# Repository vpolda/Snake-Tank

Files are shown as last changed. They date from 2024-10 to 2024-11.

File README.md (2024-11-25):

# Snake Tank

A temperature and humidity monitoring system primarly used for reptile terrariums. 

## Description

A custom ESP32-S3 PCB for temperature and humidity monitoring, along with camera monitoring. Supports up to four (4) external DHT11 sensors. The data can either be monitored through the onboard LCD display or remotely on a wifi device through Arduino Cloud. Two ESP32 Camera modules are attached externally for live video feed.

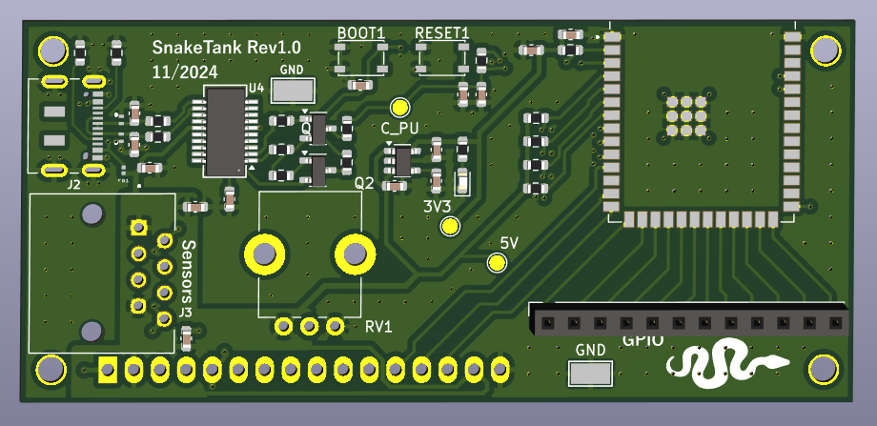
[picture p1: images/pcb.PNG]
SnakeTank PCB in KiCad 3D View SnakeTank PCB in KiCAD 3D viewer


## Design

It currently uses an ESP32-S3-WROOM-1-N8 along with module DHT11 sensors. The DHT11s where chosen for affordability and the need for general accuracy, not precision.
The DHT11 sensors are attached through an RJ45 port and an ethernet cable. These were chosen for their widely avaible nature and simplicity.
An onboard LCD screen is used to check sensor readings at any time. 
The Arduino Cloud was chosen for remote access to the available data due to ease of use and simplistic nature.

The ESP32 cameras were selected for their independence with the ability to host their own webserver or connect to another remote server. While an onboard/connection is preferred, the simpliticy and power management setup would be easier to do.

A custom four layer PCB was designed for this project using a Signal+power/GND/GND/Signal+power stackup. This was done as a learning exercise for PCB best practices. The LCD screen is on the bottom side of the board to minimize PCB size.

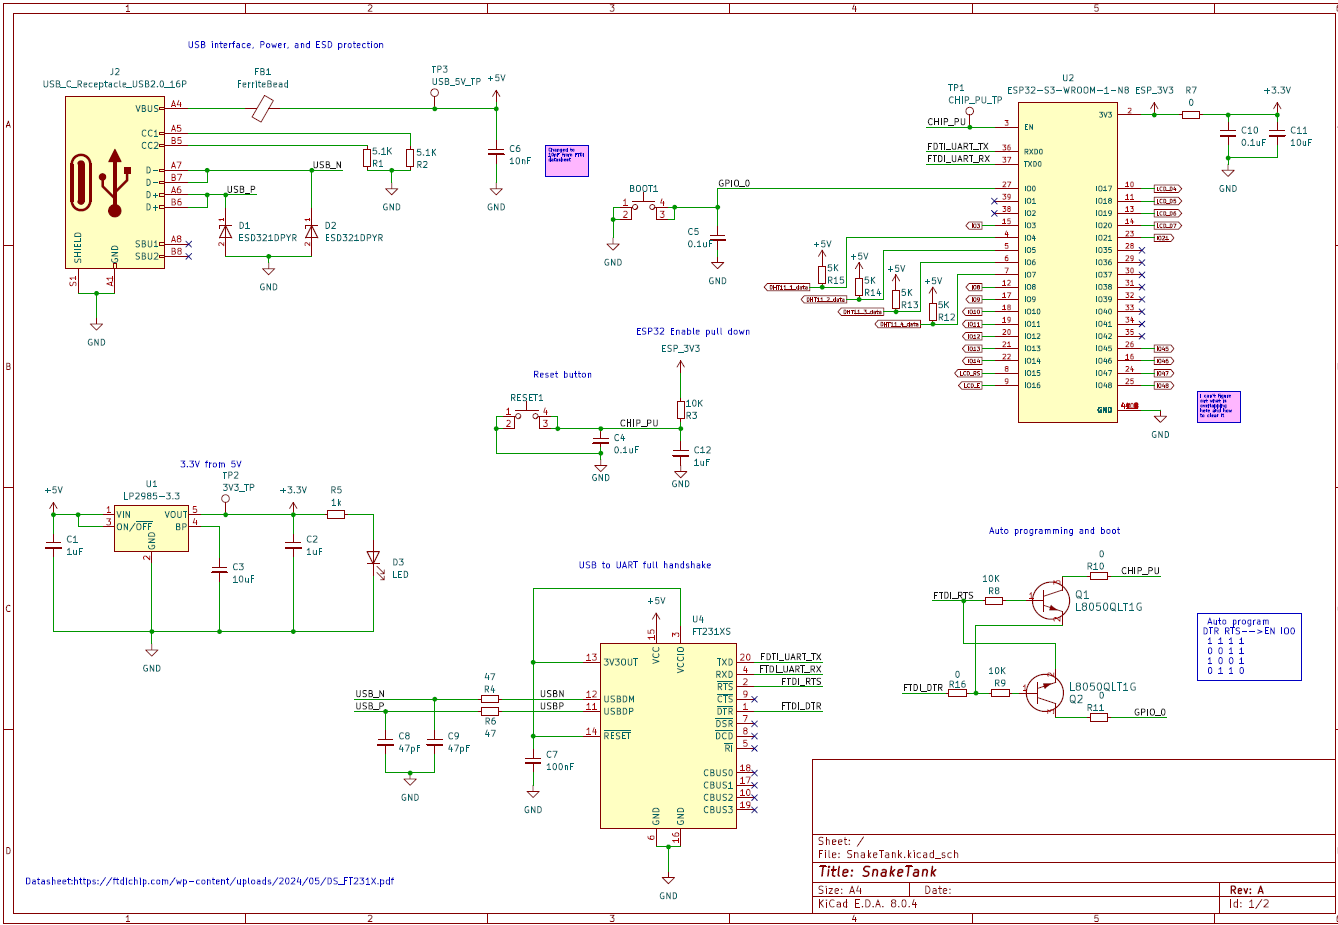
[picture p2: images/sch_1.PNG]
SnakeTank PCB Schematic Main

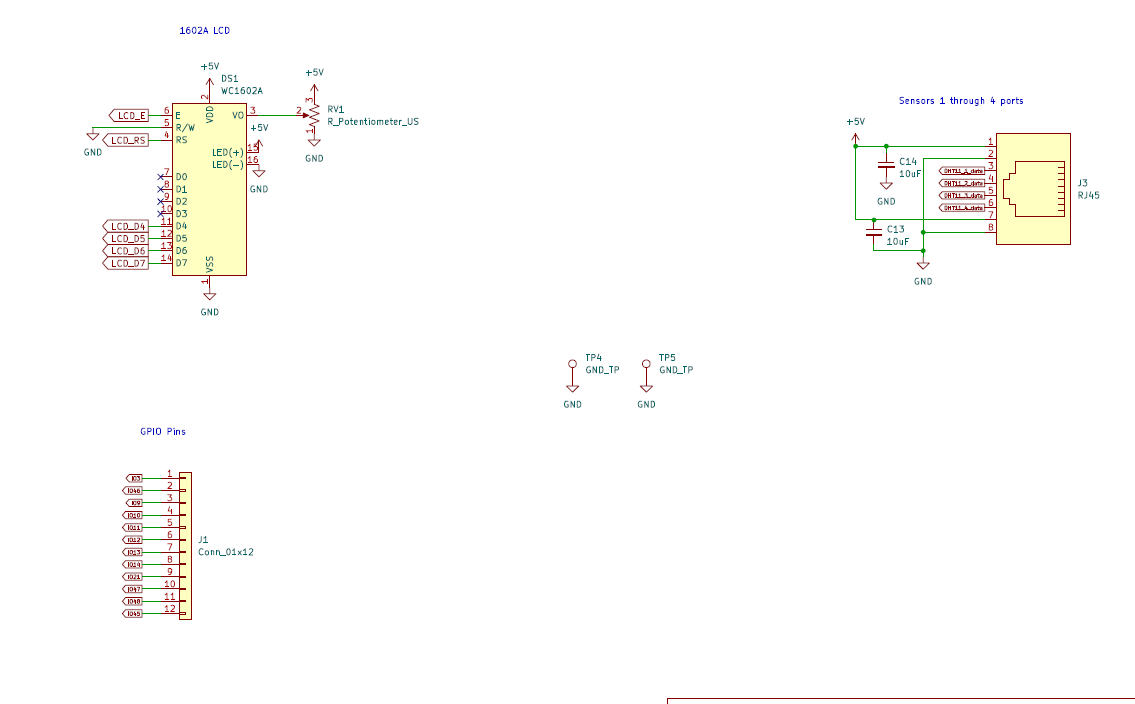
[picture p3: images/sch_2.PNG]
SnakeTank PCB Schematic Peripherals SnakeTank PCB Schematic Periphs


## Getting Started

### File Structure
- Camera - Arduino code for each ESP32 camera. 
   - ESP32_camera_webserverHost: Hosting a webserver locally on each MCU

- Hardware
   - Datasheets: Self explain
   - KiCAD: Kicad project files for custom PCB w/ ESP32
   - snakeTank_currentEstimate: Power estimate SS
 
- Software
   - Integration: combining software modules
   - OnboardDisplay: tests of the 1602A
   - LCD_interrupt: Displaying on 1602 through Arduino interrupts and timers 
   - SensorReading: reading from the dht11 modules testing
   - Camera: code for separate external esp32 cameras
  
### Dependencies

### Installing

### Executing program

## Help

## Authors

Victoria Polda
www.linkedin.com/in/victoriapolda

## Version History

* 0.1
    * Initial Release

## License

MIT License

Copyright (c) 2024 Victoria Polda

Permission is hereby granted, free of charge, to any person obtaining a copy
of this software and associated documentation files (the "Software"), to deal
in the Software without restriction, including without limitation the rights
to use, copy, modify, merge, publish, distribute, sublicense, and/or sell
copies of the Software, and to permit persons to whom the Software is
furnished to do so, subject to the following conditions:

The above copyright notice and this permission notice shall be included in all
copies or substantial portions of the Software.

THE SOFTWARE IS PROVIDED "AS IS", WITHOUT WARRANTY OF ANY KIND, EXPRESS OR
IMPLIED, INCLUDING BUT NOT LIMITED TO THE WARRANTIES OF MERCHANTABILITY,
FITNESS FOR A PARTICULAR PURPOSE AND NONINFRINGEMENT. IN NO EVENT SHALL THE
AUTHORS OR COPYRIGHT HOLDERS BE LIABLE FOR ANY CLAIM, DAMAGES OR OTHER
LIABILITY, WHETHER IN AN ACTION OF CONTRACT, TORT OR OTHERWISE, ARISING FROM,
OUT OF OR IN CONNECTION WITH THE SOFTWARE OR THE USE OR OTHER DEALINGS IN THE
SOFTWARE.

## Acknowledgments

Inspired by my Ghost corn snake Kynes :)

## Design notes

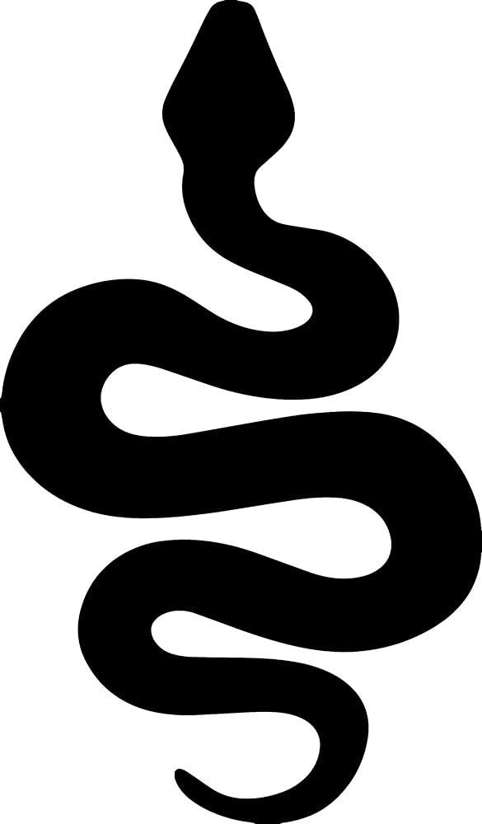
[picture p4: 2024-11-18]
Hardware/graphics/snake_filled.jpg

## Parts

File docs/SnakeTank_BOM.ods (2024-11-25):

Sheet: SnakeTank PCB
Id | Designator | Footprint | Quantity | Designation | Supplier and ref
1 | R5 | R_0603_1608Metric | 1 | 1k
2 | R16,R7,R11,R10 | R_0603_1608Metric | 4 | 0
3 | C5,C10,C4 | C_0603_1608Metric | 3 | 0.1uF
4 | C14,C3,C11,C13 | C_0603_1608Metric | 4 | 10uF
5 | RESET1,BOOT1 | SW_SPST_PTS810 | 2 | ~
6 | D3 | LED_0603_1608Metric | 1 | LED
7 | C8,C9 | C_0603_1608Metric | 2 | 47pF
8 | D2,D1 | TVS_ESD321DPYR | 2 | ESD321DPYR
9 | R13,R15,R12,R14 | R_0603_1608Metric | 4 | 5K
10 | U4 | SSOP-20_3.9x8.7mm_P0.635mm | 1 | FT231XS
11 | R1,R2 | R_0603_1608Metric | 2 | 5.1K
12 | RV1 | Potentiometer_Bourns_PTV09A-1_Single_Vertical | 1 | R_Potentiometer_US
13 | J1 | PinSocket_1x12_P2.54mm_Vertical | 1 | Conn_01x12
14 | 3V3 | TestPoint_Pad_D1.5mm | 1 | 3V3_TP
15 | C12,C2,C1 | C_0603_1608Metric | 3 | 1uF
16 | R9,R8,R3 | R_0603_1608Metric | 3 | 10K
17 | C_PU | TestPoint_Pad_D1.5mm | 1 | CHIP_PU_TP
18 | U1 | SOT-23-5 | 1 | LP2985-3.3
19 | GND,GND | TestPoint_Keystone_5019_Minature | 2 | GND_TP
20 | Q2,Q1 | SOT-23-3 | 2 | L8050QLT1G
21 | 5V | TestPoint_Pad_D1.5mm | 1 | USB_5V_TP
22 | R6,R4 | R_0603_1608Metric | 2 | 47
23 | U2 | XCVR_ESP32-S3-WROOM-1-N8 | 1 | ESP32-S3-WROOM-1-N8
24 | C7 | C_0603_1608Metric | 1 | 100nF
25 | J3 | AMPHENOL_RJE881880100 | 1 | RJ45
26 | FB1 | BEADC0603X33N | 1 | FerriteBead
27 | C6 | C_0603_1608Metric | 1 | 10nF
28 | J2 | USB_C_Receptacle_JAE_DX07S016JA1R1500 | 1 | USB_C_Receptacle_USB2.0_16P
29 | DS1 | WC1602A | 1 | WC1602A

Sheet: External
case
esp32 camera
ethernet cable
DHT11 sensor module

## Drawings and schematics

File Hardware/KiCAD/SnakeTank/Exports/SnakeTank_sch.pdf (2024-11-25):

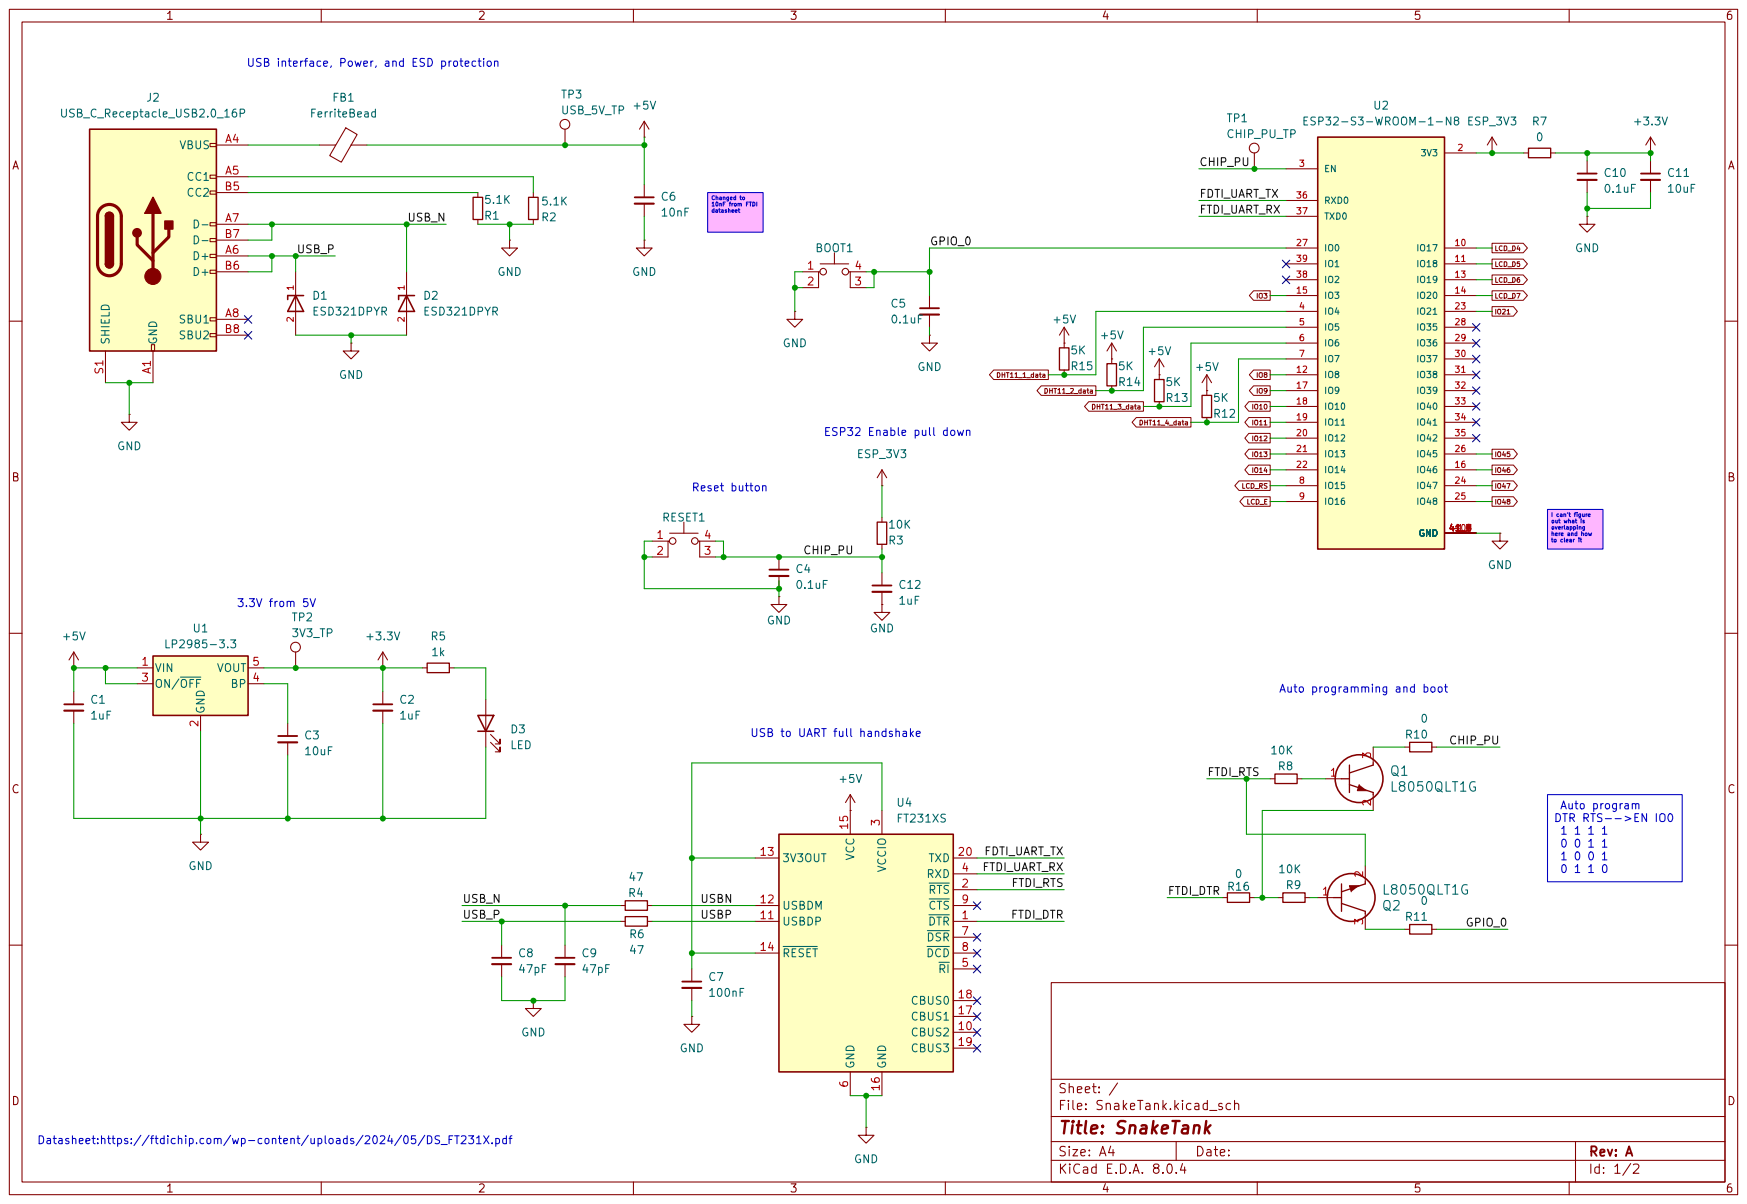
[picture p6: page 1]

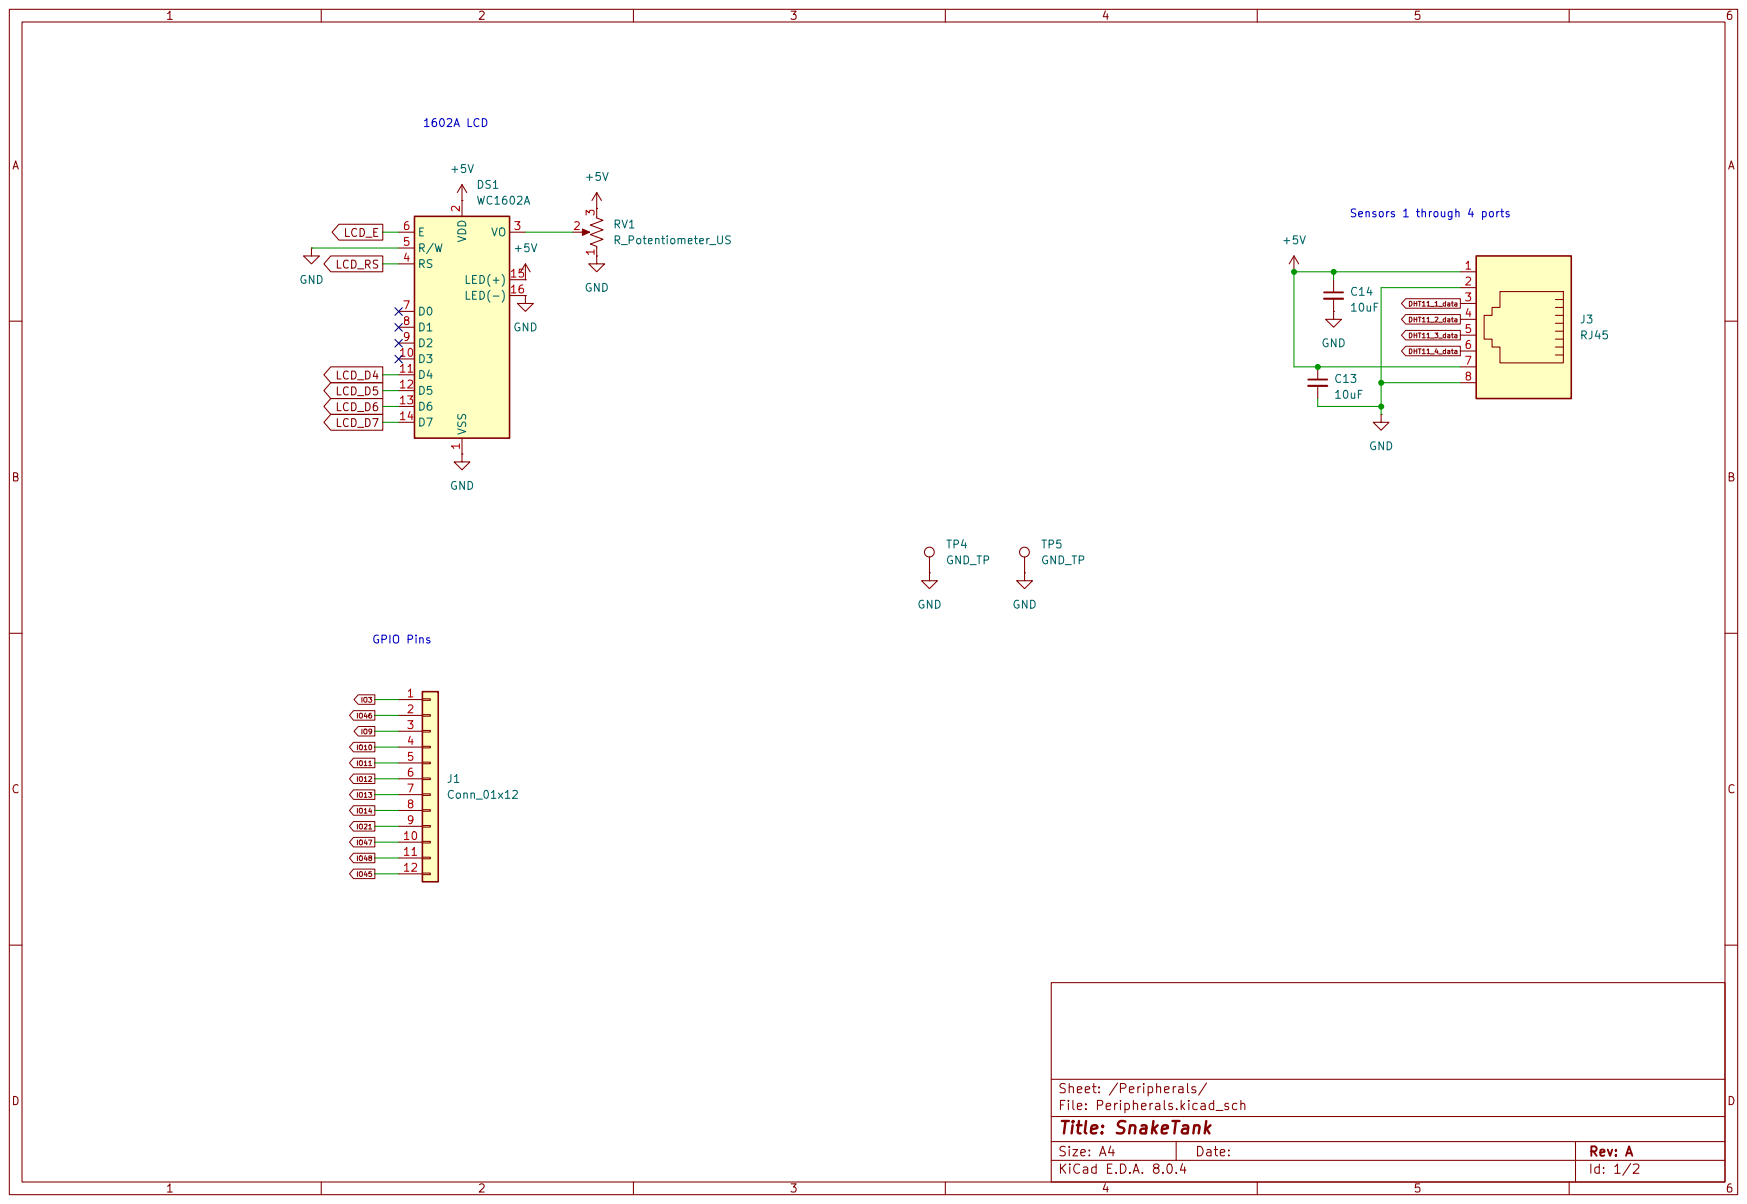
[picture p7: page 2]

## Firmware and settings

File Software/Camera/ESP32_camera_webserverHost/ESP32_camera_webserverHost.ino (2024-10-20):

//Script to connect ESP32 camera to wifi and host a server at 

// Load Wi-Fi library
#include <WiFi.h>

// Replace with your network credentials
const char* ssid = "Embedded_Government_Microchip_#1";
const char* password = "El3ctr0n1csBe4tsCS!";

// Set your Static IP address
IPAddress local_IP(192, 168, 1, 184);
// Set your Gateway IP address
IPAddress gateway(192, 168, 1, 1);
IPAddress subnet(255, 255, 0, 0);
IPAddress primaryDNS(8, 8, 8, 8); //optional
IPAddress secondaryDNS(8, 8, 4, 4); //optional

// Set web server port number to 80
WiFiServer server(80);

// Variable to store the HTTP request
String header;

// Auxiliar variables to store the current output state
String output26State = "off";
String output27State = "off";

// Assign output variables to GPIO pins
const int output26 = 26;
const int output27 = 27;

// Current time
unsigned long currentTime = millis();
// Previous time
unsigned long previousTime = 0; 
// Define timeout time in milliseconds (example: 2000ms = 2s)
const long timeoutTime = 2000;

void setup() {
  Serial.begin(115200);
  // Initialize the output variables as outputs
  pinMode(output26, OUTPUT);
  pinMode(output27, OUTPUT);
  // Set outputs to LOW
  digitalWrite(output26, LOW);
  digitalWrite(output27, LOW);

  if(!WiFi.config(local_IP, gateway, subnet, primaryDNS, secondaryDNS)) {
    Serial.println("STA Failed to configure");
  }
  WiFi.begin(ssid, password);

  // Connect to Wi-Fi network with SSID and password
  Serial.print("Connecting to ");
  Serial.println(ssid);
  WiFi.begin(ssid, password);
  while (WiFi.status() != WL_CONNECTED) {
    delay(500);
    Serial.print(".");
  }
  // Print local IP address and start web server
  Serial.println("");
  Serial.println("WiFi connected.");
  Serial.println("IP address: ");
  Serial.println(WiFi.localIP());
  server.begin();
}

void loop(){
  WiFiClient client = server.available();   // Listen for incoming clients

  if (client) {                             // If a new client connects,
    currentTime = millis();
    previousTime = currentTime;
    Serial.println("New Client.");          // print a message out in the serial port
    String currentLine = "";                // make a String to hold incoming data from the client
    while (client.connected() && currentTime - previousTime <= timeoutTime) {  // loop while the client's connected
      currentTime = millis();
      if (client.available()) {             // if there's bytes to read from the client,
        char c = client.read();             // read a byte, then
        Serial.write(c);                    // print it out the serial monitor
        header += c;
        if (c == '\n') {                    // if the byte is a newline character
          // if the current line is blank, you got two newline characters in a row.
          // that's the end of the client HTTP request, so send a response:
          if (currentLine.length() == 0) {
            // HTTP headers always start with a response code (e.g. HTTP/1.1 200 OK)
            // and a content-type so the client knows what's coming, then a blank line:
            client.println("HTTP/1.1 200 OK");
            client.println("Content-type:text/html");
            client.println("Connection: close");
            client.println();
            
            // turns the GPIOs on and off
            if (header.indexOf("GET /26/on") >= 0) {
              Serial.println("GPIO 26 on");
              output26State = "on";
              digitalWrite(output26, HIGH);
            } else if (header.indexOf("GET /26/off") >= 0) {
              Serial.println("GPIO 26 off");
              output26State = "off";
              digitalWrite(output26, LOW);
            } else if (header.indexOf("GET /27/on") >= 0) {
              Serial.println("GPIO 27 on");
              output27State = "on";
              digitalWrite(output27, HIGH);
            } else if (header.indexOf("GET /27/off") >= 0) {
              Serial.println("GPIO 27 off");
              output27State = "off";
              digitalWrite(output27, LOW);
            }
            
            // Display the HTML web page
            client.println("<!DOCTYPE html><html>");
            client.println("<head><meta name=\"viewport\" content=\"width=device-width, initial-scale=1\">");
            client.println("<link rel=\"icon\" href=\"data:,\">");
            // CSS to style the on/off buttons 
            // Feel free to change the background-color and font-size attributes to fit your preferences
            client.println("<style>html { font-family: Helvetica; display: inline-block; margin: 0px auto; text-align: center;}");
            client.println(".button { background-color: #4CAF50; border: none; color: white; padding: 16px 40px;");
            client.println("text-decoration: none; font-size: 30px; margin: 2px; cursor: pointer;}");
            client.println(".button2 {background-color: #555555;}</style></head>");
            
            // Web Page Heading
            client.println("<body><h1>ESP32 Web Server</h1>");
            
            // Display current state, and ON/OFF buttons for GPIO 26  
            client.println("<p>GPIO 26 - State " + output26State + "</p>");
            // If the output26State is off, it displays the ON button       
            if (output26State=="off") {
              client.println("<p><a href=\"/26/on\"><button class=\"button\">ON</button></a></p>");
            } else {
              client.println("<p><a href=\"/26/off\"><button class=\"button button2\">OFF</button></a></p>");
            } 
               
            // Display current state, and ON/OFF buttons for GPIO 27  
            client.println("<p>GPIO 27 - State " + output27State + "</p>");
            // If the output27State is off, it displays the ON button       
            if (output27State=="off") {
              client.println("<p><a href=\"/27/on\"><button class=\"button\">ON</button></a></p>");
            } else {
              client.println("<p><a href=\"/27/off\"><button class=\"button button2\">OFF</button></a></p>");
            }
            client.println("</body></html>");
            
            // The HTTP response ends with another blank line
            client.println();
            // Break out of the while loop
            break;
          } else { // if you got a newline, then clear currentLine
            currentLine = "";
          }
        } else if (c != '\r') {  // if you got anything else but a carriage return character,
          currentLine += c;      // add it to the end of the currentLine
        }
      }
    }
    // Clear the header variable
    header = "";
    // Close the connection
    client.stop();
    Serial.println("Client disconnected.");
    Serial.println("");
  }
}

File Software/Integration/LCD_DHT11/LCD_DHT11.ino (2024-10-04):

//This script tests updating the LCD screen based on interrupts 
//instead of the delay function

// LCD stuff
#include <LiquidCrystal.h>
 
// initialize the library with the numbers of the interface pins
//Goes RS, E, D4,D5,D6,D7
LiquidCrystal lcd(45, 35, 38, 39, 40, 41);

//Sensor stuff
#include <DHT11.h>

DHT11 dht1(4);
DHT11 dht2(6);

int temperature1 = 0;
int humidity1 = 0;

int temperature2 = 0;
int humidity2 = 0;

int result1 = 0;
int result2 = 0;

//Timer stuff
#include <SimpleTimer.h>
SimpleTimer lcdTimer(5000);

void setup()
{
  Serial.begin(115200);
  // set up the LCD's number of columns and rows (c,r), only do this once on setup
  lcd.begin(16, 2);
  //row 0 = first
  lcd.setCursor(0, 0);
  // Print a message to the LCD.
  lcd.print("Dual Reading");
  //Move to second row for data
}

void loop() {
  if (lcdTimer.isReady()) {            // Check is ready a first timer
    //Serial.println("5 seconds have passed");
    lcdTimer.reset();  

    lcd.clear();

    //Sensor 1
    //Read temp and humidity
    int result1 = dht1.readTemperatureHumidity(temperature1, humidity1);

    lcd.setCursor(0, 0);

    if (result1 == 0) {
      lcd.print("T1:");
      lcd.print(temperature1);
      lcd.print("C H1:");
      lcd.print(humidity1);
    } else {
      // Print error message based on the error code.
      lcd.print(DHT11::getErrorString(result1));
    }

    //Sensor 2
    
    //Read temp and humidity
    int result2 = dht2.readTemperatureHumidity(temperature2, humidity2);

    lcd.setCursor(0, 1);

    if (result2 == 0) {
      lcd.print("T2:");
      lcd.print(temperature2);
      lcd.print("C H2:");
      lcd.print(humidity2);
    } else {
      // Print error message based on the error code.
      lcd.print(DHT11::getErrorString(result2));
    }
  }
}

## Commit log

2024-08-08 Create DHT11_test_arduino.ino
    Reads from DHT11 sensor with both an ES32-S3 or Arduino.
2024-08-22 LCD tests
    Adding LCD test files and interrupts
2024-08-26 LCD and integration test
    Added LCD display based on interrupt timer. Add integration test between LCD and DHT11 sensors
2024-08-27 KiCad Hardware files
    Adding KiCad schematic and layout files. Initial project files commit
    [SnakeTank.kicad_pcb, SnakeTank.kicad_sch]
2024-08-30 Lots of hardware updates
    [SnakeTank.kicad_sch, untitled.kicad_sch]
2024-09-03 Updated schematic and export PDF
    [SnakeTank.kicad_sch, untitled.kicad_sch]
2024-09-03 Create Arduino Device Secret Key (1).pdf
    For backup
2024-10-04 hardware work
    finishing schematic and footprints
    [Peripherals.kicad_sch, SnakeTank.kicad_pcb, SnakeTank.kicad_sch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]
2024-10-20 layout Rough
    [Peripherals.kicad_sch, SnakeTank.kicad_sch, SnakeTank_4_sig_pwr_gnd_sig.kicad_pcb]
2024-10-27 WOOOHOO
    rough draft of layout done
    [Peripherals.kicad_sch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]
2024-11-18 Hw tweaks
    [SnakeTank-B_Cu.gbr, SnakeTank-B_Mask.gbr, SnakeTank-B_Paste.gbr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]
2024-11-20 PCB ordered rev 1
    [SnakeTank-B_Cu.gbr, SnakeTank-B_Mask.gbr, SnakeTank-B_Paste.gbr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]
2024-11-25 adding schematic images
